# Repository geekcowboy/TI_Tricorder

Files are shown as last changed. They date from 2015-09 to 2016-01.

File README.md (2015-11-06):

Prototyping the Future: The Mark I Tricorder Project

For 50 decades, Star Trek has served as an inspiration for engineers and makers alike. Many of the tech concepts of 1960s science fiction has turned into 21st century everyday reality.  One of the most beloved ideas was the all-in-one Tricorder that let the crew ascertain the status of countless environmental factors. The Tricorder of the Captain Kirk and Mr. Spock may still be a few generations away, but what if the Mark I version of the Tricorder was invented tody?

This project presents one intriguing possibility.  Highlighting the amazing micrcontroller and sensor technology of today, we've built a Mark I Tricorder prototype.  Leveraging the out-of-this-world capabilities of the new TI MSP432P401R LaunchPad, we've put a ton of sensors in a conventient BoosterPack form factor.

Some highlights of the Tricorder BoosterPack:

- HDC1000 Humidity Sensor
- LMT70 Temperature Sensor
- OPT3001 Ambient Light Sensor
- MAG3110 Magnetometer
- LMP91000 Electrochemical Sensor Interface
- PGA900 Programmable Resistive Sensing Conditioner
- microSD Card reader
- Peripheral Module (Pmod) Type I GPIO Interface 
- 2 user defined buttons / 1 reset button
- 2 user defined LEDs / 1 power indicator LED

Coming Soon:  Shopping Cart BOM @ Mouser Electronics

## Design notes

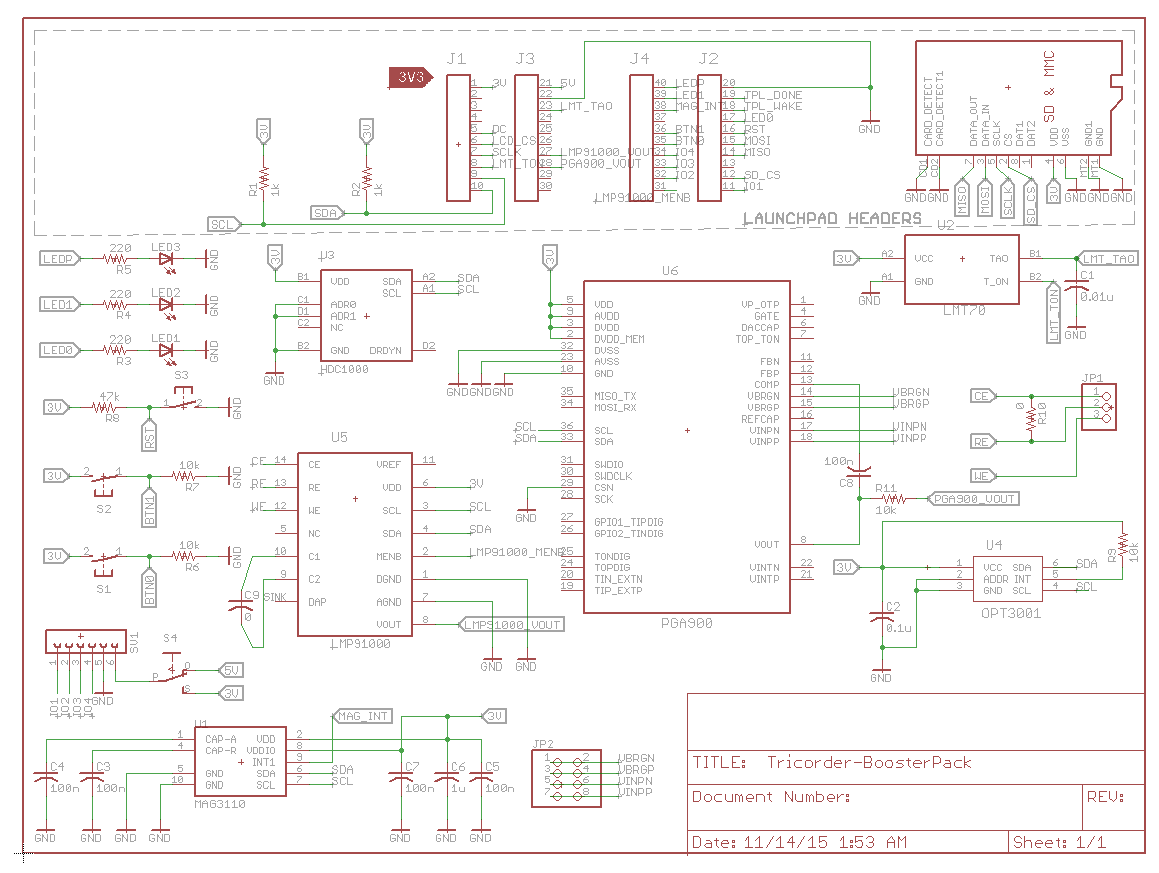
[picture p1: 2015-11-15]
Documentation/v1_1/Tricorder_Schematic_v1_1.png

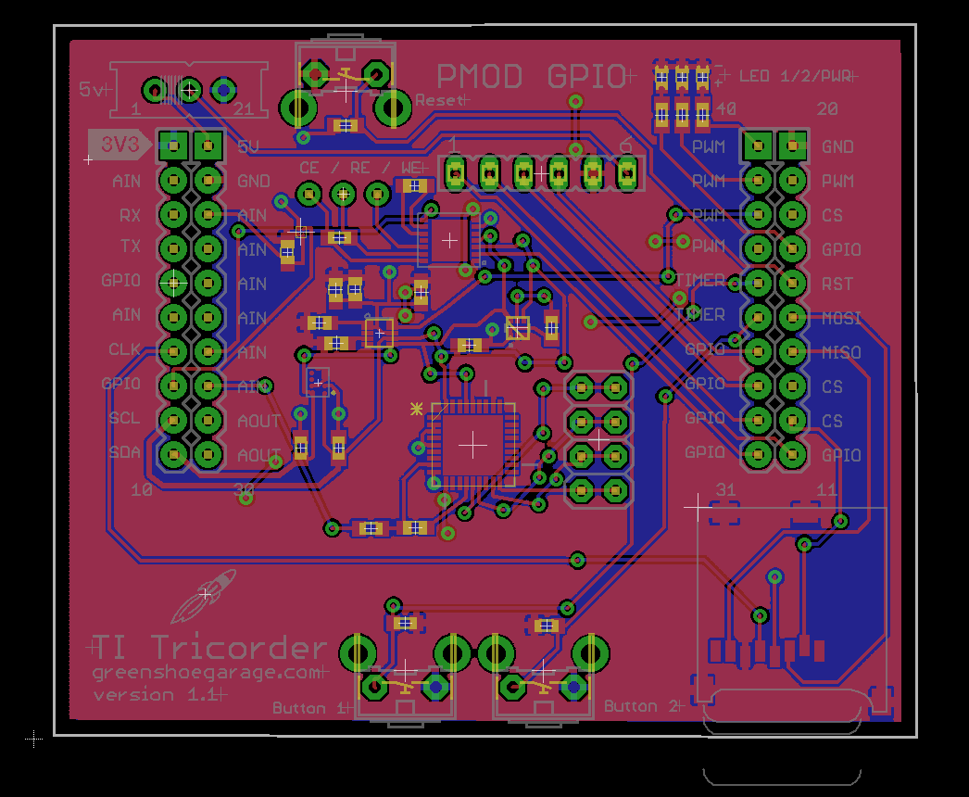
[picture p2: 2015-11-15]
Documentation/v1_1/Tricorder_PCB_Layout_v1_1.png

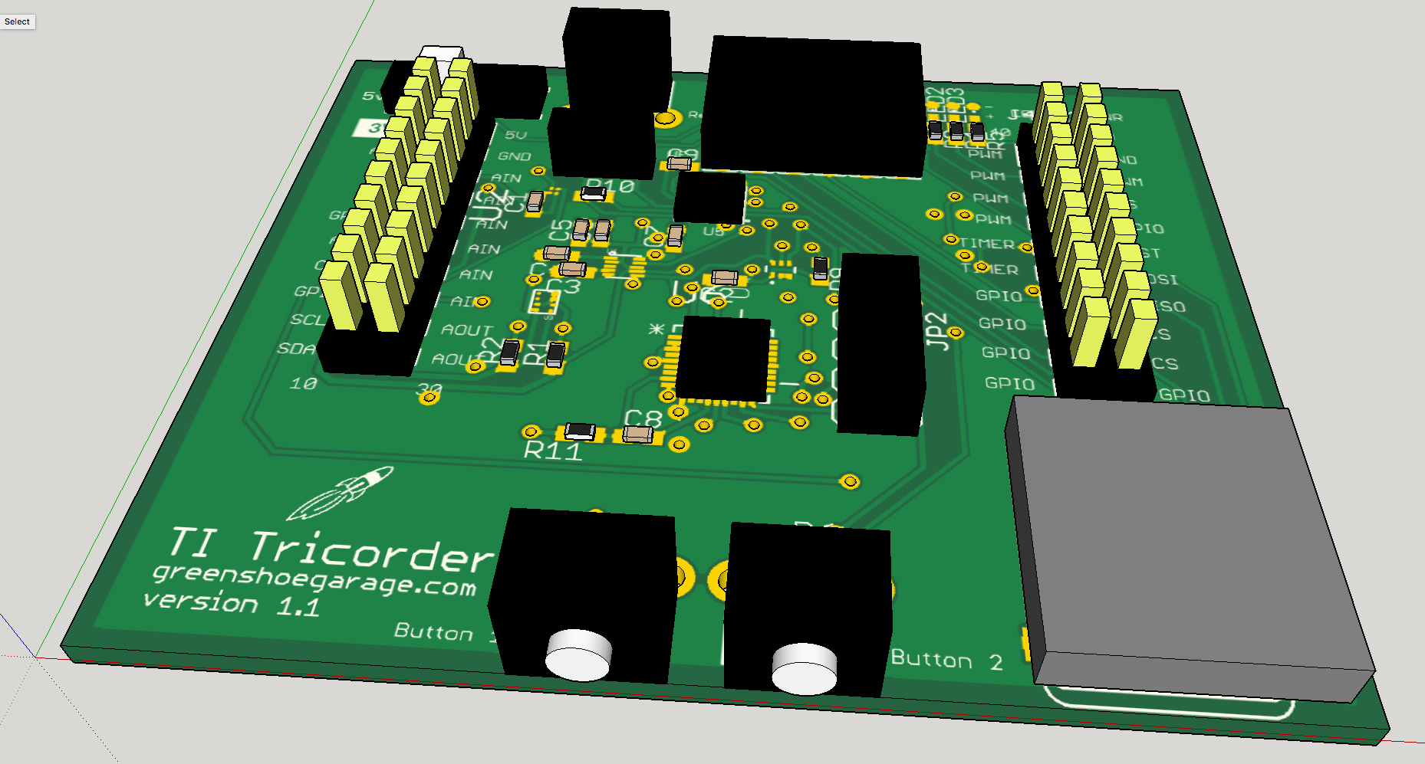
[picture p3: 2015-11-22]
Documentation/v1_1/PCBA_3D_v1_1.png

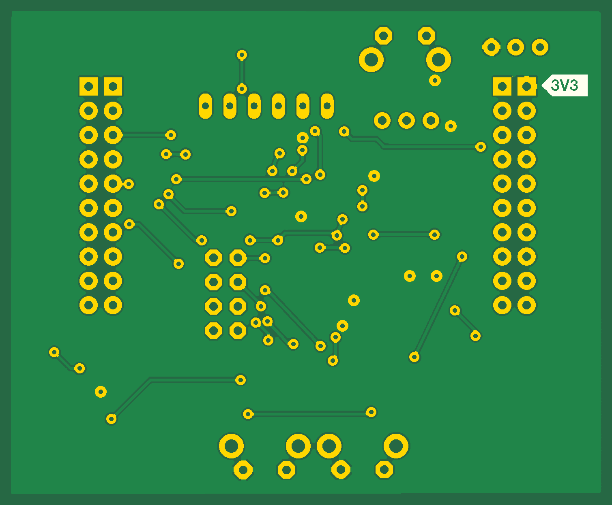
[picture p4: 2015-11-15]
EAGLE BoosterPack/v1_1/eagleUp/eagleUp_Tricorder-BoosterPack_board_bottom.png

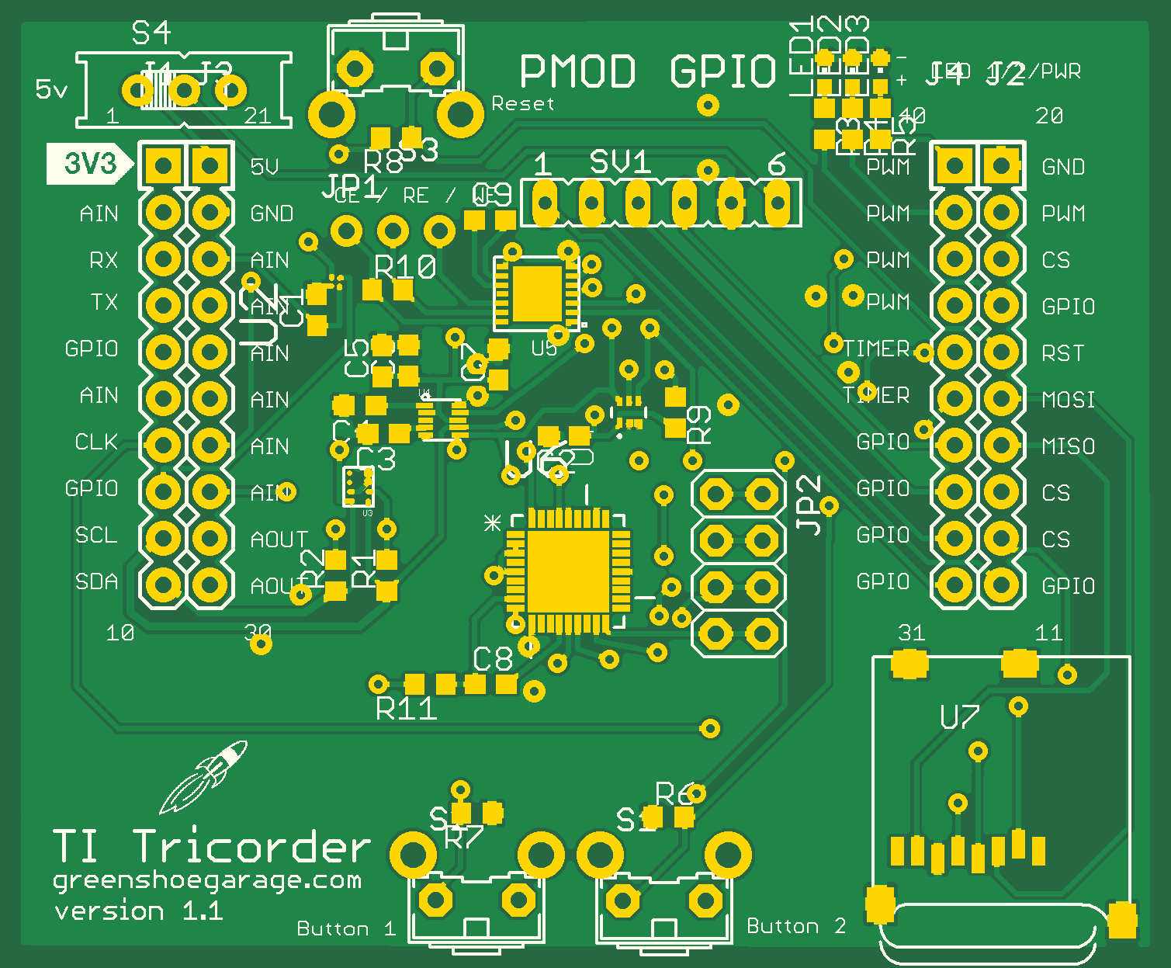
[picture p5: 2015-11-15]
EAGLE BoosterPack/v1_1/eagleUp/eagleUp_Tricorder-BoosterPack_board_top.png

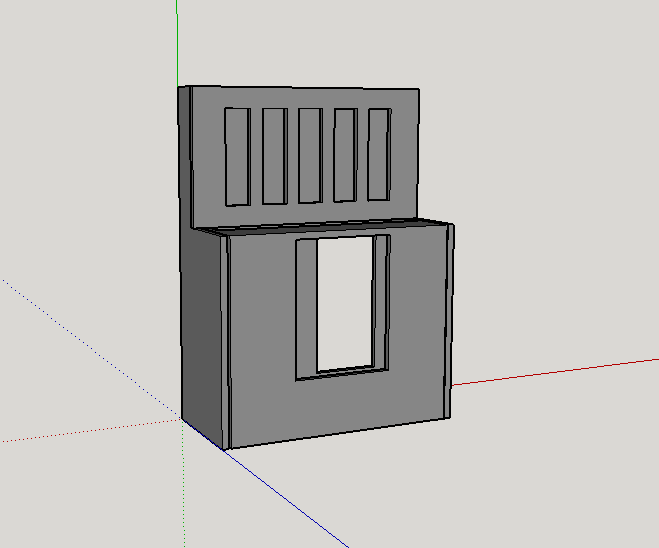
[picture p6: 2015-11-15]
Documentation/v1_1/Enclosure_3D_v1_1.png

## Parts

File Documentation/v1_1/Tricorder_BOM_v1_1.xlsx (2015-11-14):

Qty | Part | Value | Device | Package | Description | Manufacturer | Mfr Part # | Notes | SMD Caps | 8
2 | A1, A2 |  | HEADER2X10-BOOSTERPACK | SSHQ-110-D-08-G-LF | STACKABLE HEADERS, 2x10 (QTY: 2) | Major Leage Electronics | SSHQ-110-D-10-G-LF |  | SMD Resistor | 11
1 | C1 | 0.01u | C-USC0603 | C0603 | CAPACITOR, American symbol | Kemet | C0603C103K5RACTU |  | Headers | 5
6 | C2, C3, C4, C5, C7, C8 | 100n | C-USC0603 | C0603 | CAPACITOR, American symbol | Kemet | C0603C104K5RACTU |  | Switches | 1
1 | C6 | 1u | C-USC0603 | C0603 | CAPACITOR, American symbol | Kemet | C0603C105K4RACTU |  | Ics | 6
1 | C9 | DNP | C-USC0603 | C0603 | CAPACITOR, American symbol | DNP | Do Not Populate
1 | JP1 |  | PINHD-1X3 | FEMALE 1X03 | FEMALE HEADER | Sullins | PPPC031LFBN-RC | http://www.digikey.com/product-detail/en/PPPC031LFBN-RC/S7036-ND/810175
1 | JP2 |  | PINHD-2X4 | FEMALE 2X04 | FEMALE HEADER | Sullins | PPTC042LFBN-RC | http://www.digikey.com/product-detail/en/PPTC042LFBN-RC/S7072-ND/810211
2 | LED1, LED2 |  | LEDCHIPLED_0603 | CHIPLED_0603 | RED LED | Avago | HSMH-C190
1 | LED3 |  | LEDCHIPLED_0603 | CHIPLED_0603 | GREEN LED | Avago | HSMG-C190
2 | R1, R2 | 1k | R-US_R0603 | R0603 | RESISTOR | Vishay | CRCW06031K00FKEA
3 | R3 R4, R5 | 220 | R-US_R0603 | R0603 | RESISTOR | Vishay | CRCW0603220RFKEA
4 | R6, R7, R9, R11 | 10k | R-US_R0603 | R0603 | RESISTOR | Vishay | CRCW060310K0FKEA
1 | R8 | 47k | R-US_R0603 | R0603 | RESISTOR | Vishay | CRCW060347K0FKEA
1 | R10 | DNP | R-US_R0603 | R0603 | RESISTOR | DNP | Do Not Populate
3 | S1, S2, S3 |  | B3F-3100 RIGHT ANGLE BUTTON | B3F-3100 | OMRON SWITCH | Omron | B3F-3100
1 | S4 |  | EG1218S SLIDE SWITCH | EG1218S SLIDE SWITCH | SLIDING SWITCH | Eswitch | EG1218 | http://www.digikey.com/product-detail/en/EG1218/EG1903-ND/101726
1 | SV1 |  | PINHD-1X6 RIGHT ANGLE | FEMALE 1X06 RIGHT ANGLE | FEMALE RIGHT ANGLE HEADER | Sullins | PPPC061LGBN-RC | http://www.digikey.com/product-detail/en/PPPC061LGBN-RC/S5481-ND/775939
1 | U1 | MAG3110 | MAG3110 | DFN-10 | 3-axis digital (I2C) magnetometer | Freescale | MAG3110FCR1 (http://www.mouser.com/ProductDetail/Freescale-Semiconductor/MAG3110FCR1/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)
1 | U2 | LMT70 | LMT70 | BGA4C40P2X2_77X77X50 | Temperature Sensor | Texas Instruments | LMT70YFQT (http://www.mouser.com/ProductDetail/Texas-Instruments/LMT70YFQT/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)
1 | U3 | HDC1000 | HDC1000 | DSBGA_8_YPA | Humidity Sensor | Texas Instruments | HDC1000YPAT
1 | U4 | OPT3001 | OPT3001 | SOT23-6 | Ambient Light Sensor | Texas Instruments | OPT3001DNPR
1 | U5 | LMP91000 | LMP91000 | WFDFN-14 | Electrochemical Sensor Interface | Texas Instruments | LMP91000SD/NOPB
1 | U6 | PGA900 | PGA900 | QFN50P600X600X90-37N | Programmable Resistive Sensing Conditioner | Texas Instruments | PGA900ARHHT
1 | U7 | MICROSD | MICROSD | MICROSD CARD HOLDER | MicroSD Card Reader, Surface Mount | 3M | 2908-05WB-MG

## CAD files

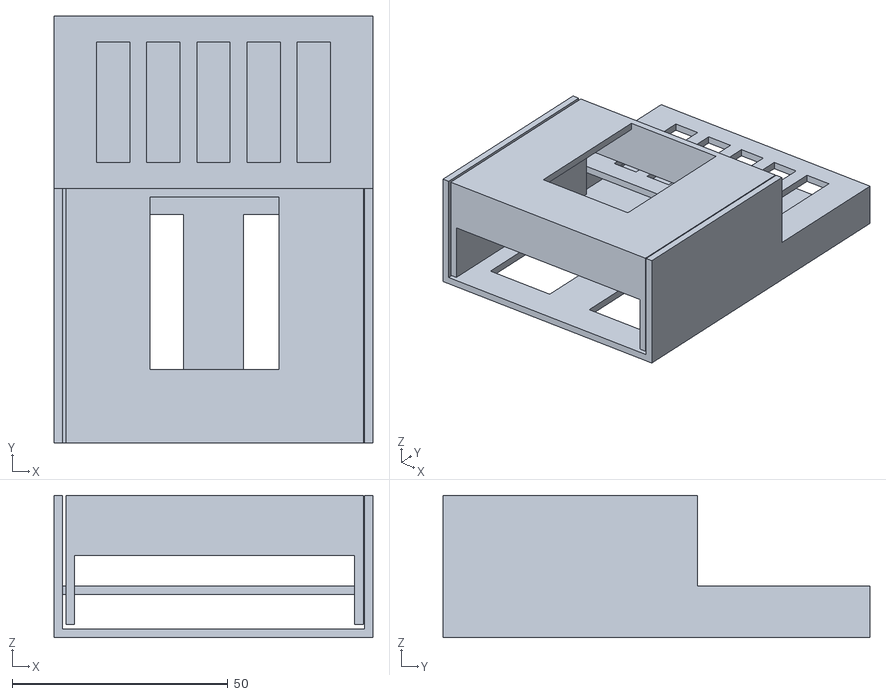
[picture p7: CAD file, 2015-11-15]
3D Files/v1_1/Tricorder_Assembled.stl
74.0 x 99.0 x 33.0

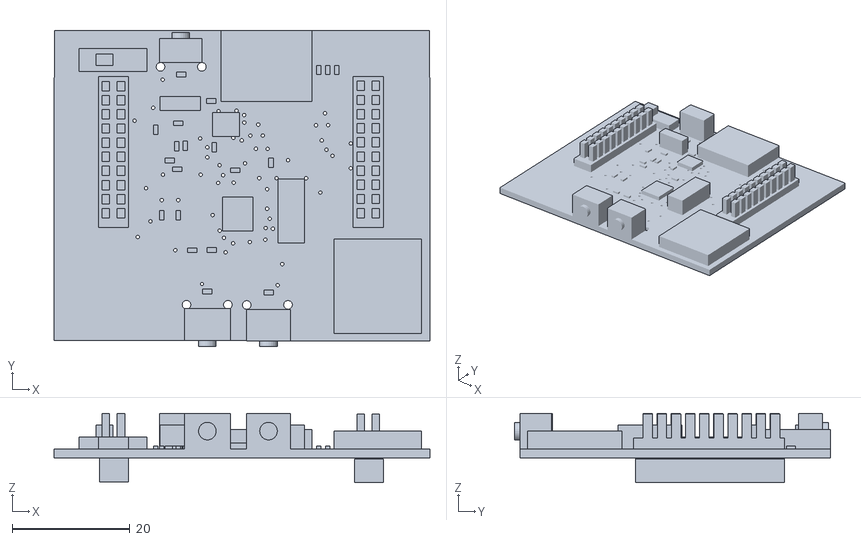
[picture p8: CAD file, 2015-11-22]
3D Files/v1_1/PCBA_v1_1.stl
63.8 x 53.7 x 11.7

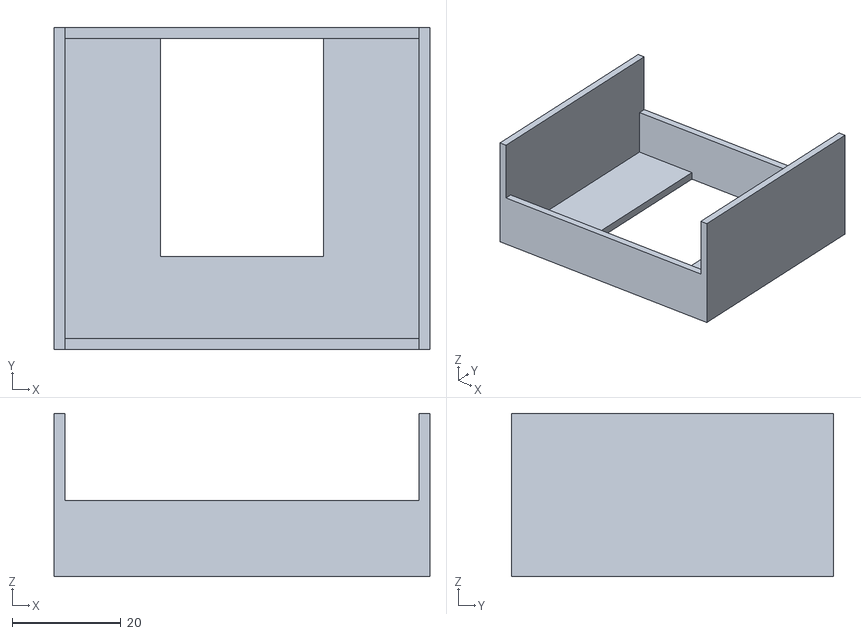
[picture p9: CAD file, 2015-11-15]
3D Files/v1_1/DisplayCase.stl
69.0 x 59.0 x 30.0

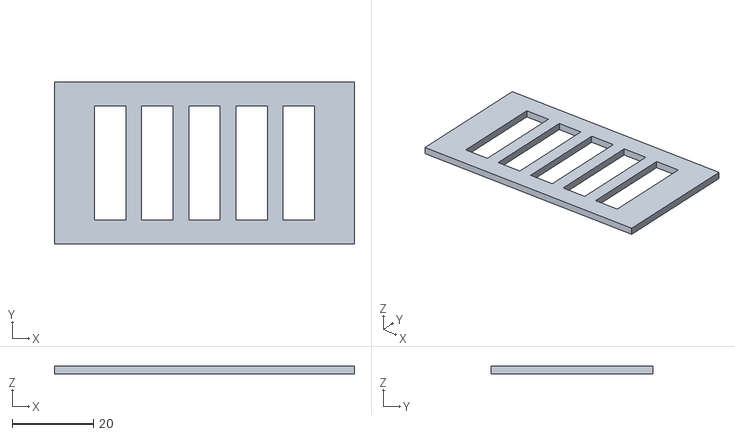
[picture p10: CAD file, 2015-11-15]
3D Files/v1_1/Tricorder_VentShield.stl
74.0 x 40.0 x 2.00

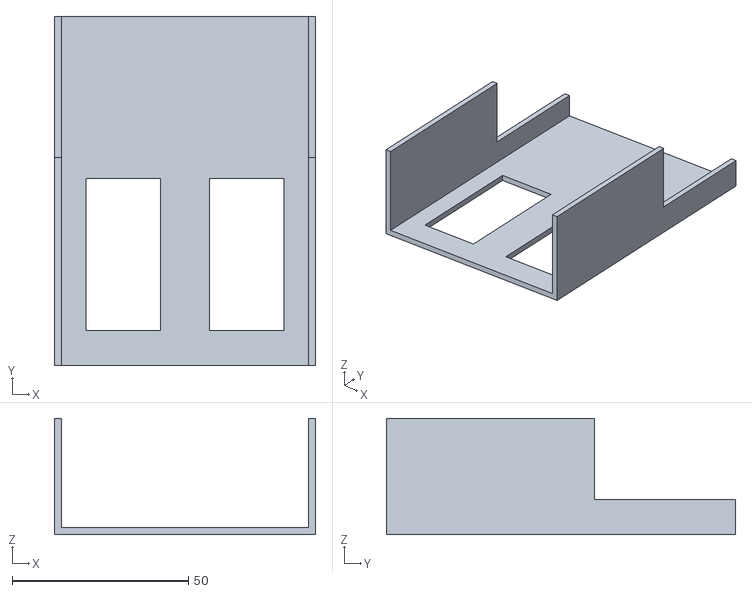
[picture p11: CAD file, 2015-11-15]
3D Files/v1_1/TricorderBottom.stl
74.0 x 99.0 x 33.0

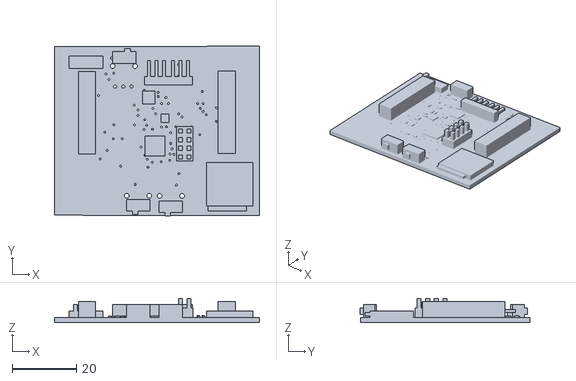
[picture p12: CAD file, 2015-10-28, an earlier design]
3D Files/v1_0/PCB_rev2_3D.stl
63.8 x 52.8 x 7.60

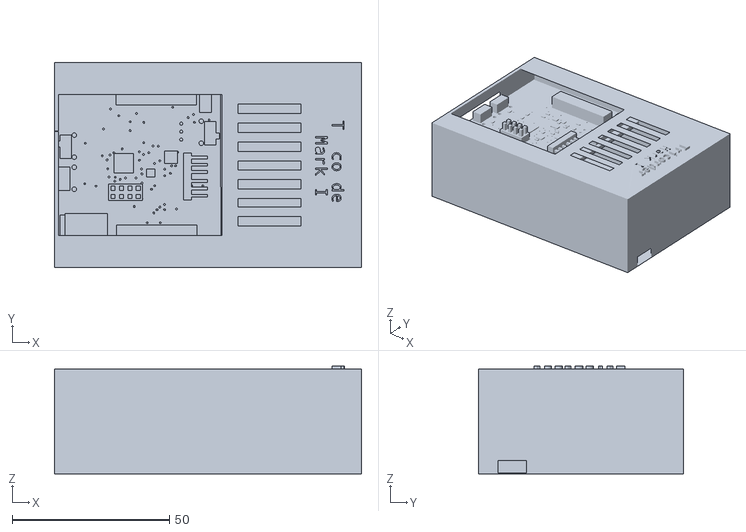
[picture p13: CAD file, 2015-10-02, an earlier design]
3D Files/v1_0/Tricorder_Concept_rev2.stl
97.6 x 65.3 x 34.3

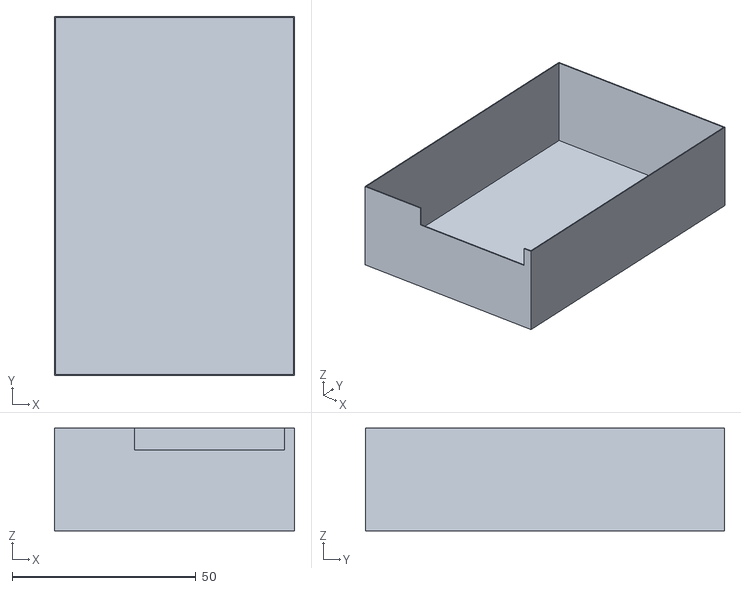
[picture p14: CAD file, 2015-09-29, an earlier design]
3D Files/v1_0/Tricorder_BottomEnclosure_rev2.stl
65.3 x 97.6 x 28.0

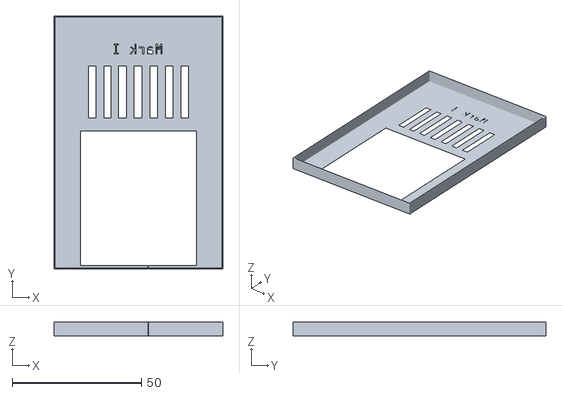
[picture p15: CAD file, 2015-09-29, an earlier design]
3D Files/v1_0/Tricorder_EnclosureTop_rev2.stl
65.3 x 97.6 x 5.33

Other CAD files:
3D Files/v1_0/PCB_rev2_3D.skp
3D Files/v1_0/Tricorder_BottomEnclosure_rev2.skp
3D Files/v1_0/Tricorder_Concept_rev2.skp
3D Files/v1_0/Tricorder_EnclosureTop_rev2.skp
3D Files/v1_1/DisplayCase.skp
3D Files/v1_1/PCBA_v1_1.skp
3D Files/v1_1/PCBA_v1_1~.skp
3D Files/v1_1/TricorderBottom.skp
3D Files/v1_1/Tricorder_Assembled.skp
3D Files/v1_1/Tricorder_VentShield.skp

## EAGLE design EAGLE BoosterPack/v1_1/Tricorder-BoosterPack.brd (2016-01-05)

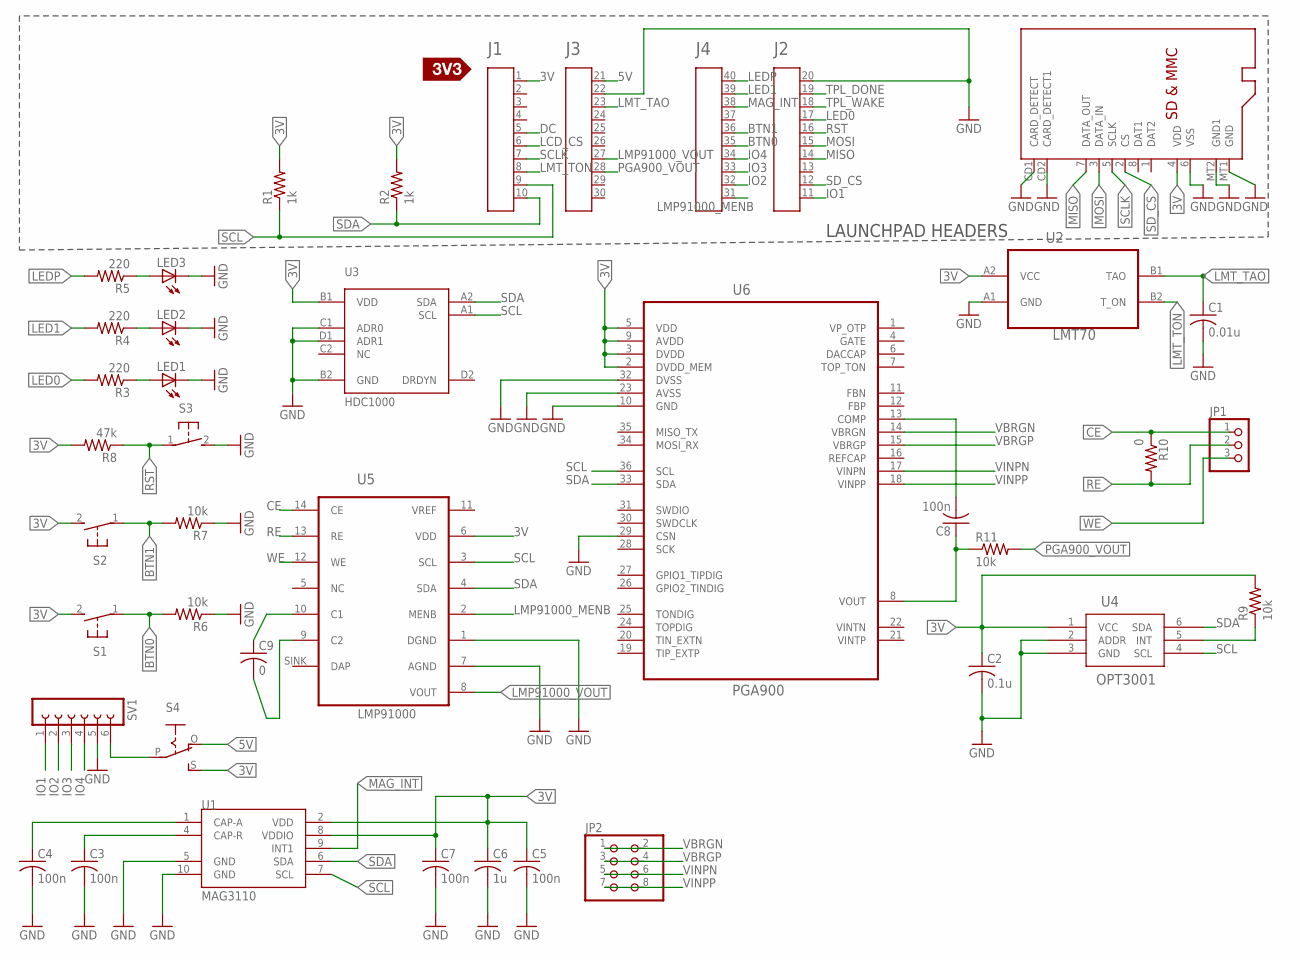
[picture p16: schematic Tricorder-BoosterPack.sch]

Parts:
A1: HEADER4X10-BOOSTERPACK; 4X10-BOOSTERPACK
C1: 0.01u; C0603
C2: 0.1u; C0603
C3, C4, C5, C7, C8: 100n; C0603
C6: 1u; C0603
C9: 0; C0603
JP1: PINHD-1X3CB; 1X03-CLEANBIG
JP2: PINHD-2X4; 2X04
LED1, LED2, LED3: LEDCHIPLED_0603; CHIPLED_0603
R1, R2: 1k; R0603
R3, R4, R5: 220; R0603
R6, R7, R9, R11: 10k; R0603
R8: 47k; R0603
R10: 0; R0603
S1, S2, S3: 31-XX; B3F-31XX
S4: EG1218S; EG1218
SV1: FE06-1; FE06
U1: MAG3110; DFN-10
U2: LMT70LMT70; BGA4C40P2X2_77X77X50
U3: HDC1000; DSBGA_8_YPA
U4: OPT3001; DPK6
U5: LMP91000; WFDFN-14; DIGIKEY LMP91000
U6: PGA900; QFN50P600X600X90-37N
U7: MICROSD
U$3: SILK_3V3_TAG

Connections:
3V: A1.1, C2.1, C5.1, C6.1, C7.1, R1.2, R2.2, R8.2, R9.2, S1.2 (S), S2.2 (S), S4.S, U1.2 (VDD), U1.8 (VDDIO), U2.A2 (VCC), U3.B1 (VDD), U4.1 (VCC), U5.6 (VDD), U6.2 (DVDD_MEM), U6.3 (DVDD), U6.5 (VDD), U6.9 (AVDD), U7.4 (VDD)
5V: A1.21, S4.O
BTN0: A1.35, R6.2, S1.1
BTN1: A1.36, R7.2, S2.1
CE: JP1.1, R10.1, U5.14 (CE)
DC: A1.5
GND: A1.20, A1.22, C1.2, C2.2, C3.2, C4.2, C5.2, C6.2, C7.2, LED1.C, LED2.C, LED3.C, R6.1, R7.1, S3.2 (S), SV1.5, U1.5 (GND), U1.10 (GND), U2.A1 (GND), U3.B2 (GND), U3.C1 (ADR0), U3.D1 (ADR1), U4.2 (ADDR), U4.3 (GND), U5.1 (DGND), U5.7 (AGND), U6.10 (GND), U6.23 (AVSS), U6.29 (CSN), U6.32 (DVSS), U7.6 (VSS), U7.CD1 (CARD_DETECT), U7.CD2 (CARD_DETECT1), U7.MT1 (GND), U7.MT2 (GND1)
IO1: A1.11, SV1.1
IO2: A1.32, SV1.2
IO3: A1.33, SV1.3
IO4: A1.34, SV1.4
LCD_CS: A1.6
LED0: A1.17, R3.2
LED1: A1.39, R4.2
LEDP: A1.40, R5.2
LMP91000_MENB: A1.31, U5.2 (MENB)
LMP91000_VOUT: A1.27, U5.8 (VOUT)
LMT_TAO: A1.23, C1.1, U2.B1 (TAO)
LMT_TON: A1.8, U2.B2 (T_ON)
MAG_INT: A1.38, U1.9 (INT1)
MISO: A1.14, U7.7 (DATA_OUT)
MOSI: A1.15, U7.3 (DATA_IN)
unnamed: LED1.A, R3.1
unnamed: LED2.A, R4.1
unnamed: LED3.A, R5.1
unnamed: S4.P, SV1.6
unnamed: R9.1, U4.5 (INT)
unnamed: C9.1, U5.10 (C1)
unnamed: C3.1, U1.4 (CAP-R)
unnamed: C4.1, U1.1 (CAP-A)
unnamed: C8.2, U6.13 (COMP)
unnamed: C9.2, U5.9 (C2)
unnamed: C8.1, R11.1, U6.8 (VOUT)
PGA900_VOUT: A1.28, R11.2
RE: JP1.2, R10.2, U5.13 (RE)
RST: A1.16, R8.1, S3.1
SCL: A1.9, R1.1, U1.7 (SCL), U3.A1 (SCL), U4.4 (SCL), U5.3 (SCL), U6.36 (SCL)
SCLK: A1.7, U7.5 (SCLK)
SDA: A1.10, R2.1, U1.6 (SDA), U3.A2 (SDA), U4.6 (SDA), U5.4 (SDA), U6.33 (SDA)
SD_CS: A1.12, U7.2 (CS)
TPL_DONE: A1.19
TPL_WAKE: A1.18
VBRGN: JP2.1, JP2.2, U6.14 (VBRGN)
VBRGP: JP2.3, JP2.4, U6.15 (VBRGP)
VINPN: JP2.5, JP2.6, U6.17 (VINPN)
VINPP: JP2.7, JP2.8, U6.18 (VINPP)
VREF: U5.11 (VREF)
WE: JP1.3, U5.12 (WE)

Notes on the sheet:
LAUNCHPAD HEADERS

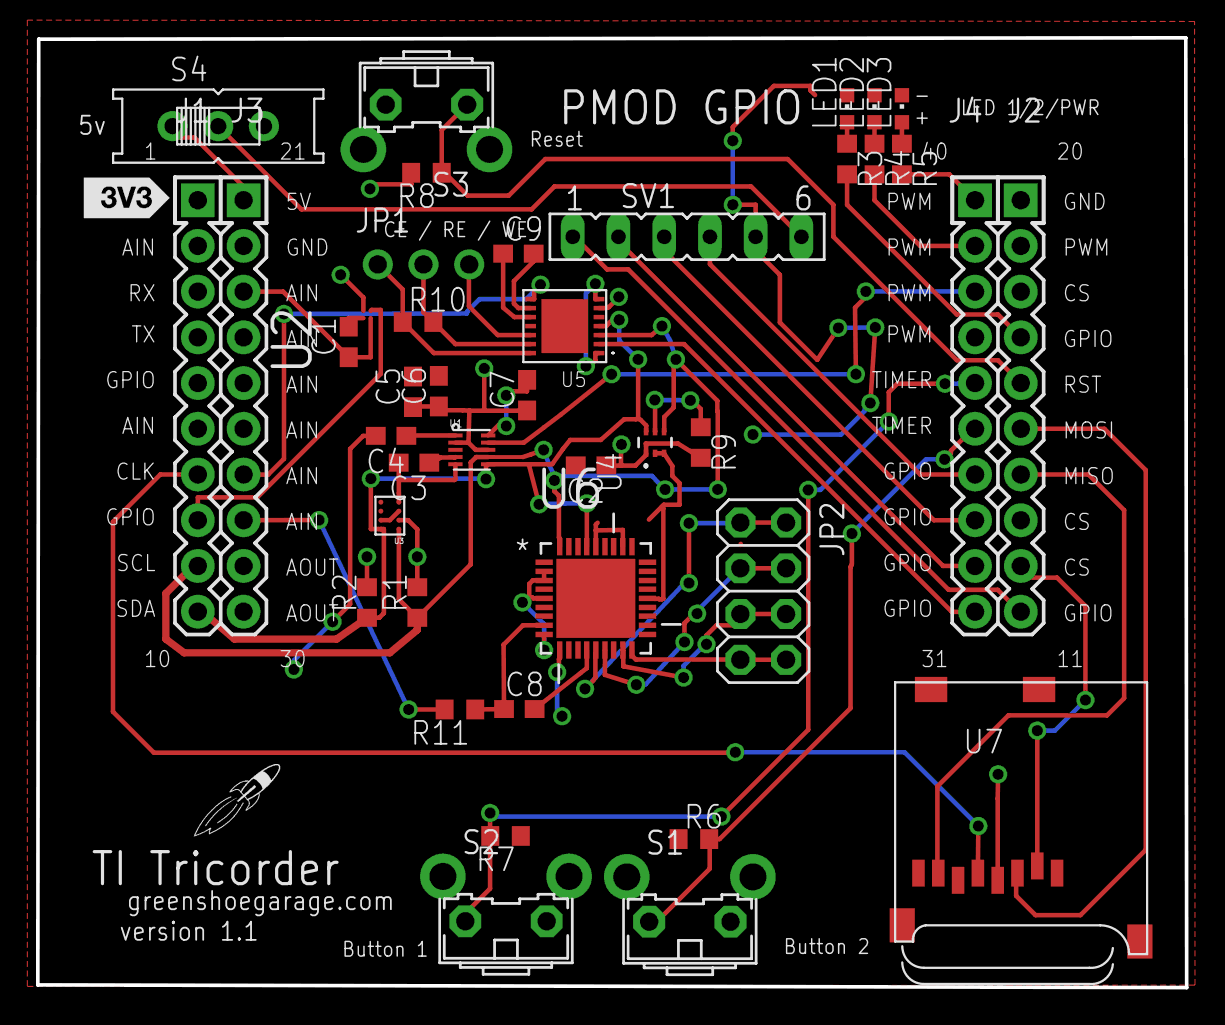
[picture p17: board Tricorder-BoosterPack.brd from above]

Board: 2 copper layers, 63.8 x 52.8 mm, 40 parts (0 on the bottom side), 43 nets.

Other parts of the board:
U$2: LOGO-ROCKET

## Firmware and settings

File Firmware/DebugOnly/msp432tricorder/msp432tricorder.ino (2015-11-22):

//
//  MSP432Tricoder
//  Example main.cpp for MSP432P401R-based Tricorder BoosterPack
//
//
//  Date   :  Sep 12, 2015
//  Version:  1.00
//  File   :  MSP432Tricorder.ino
//
//  Licence CC = BY SA NC
//
//  Use of Clock from Galaxia library for MSP432 proposed by ReiVilo
//

//
//LIBRARIES
//
#include <TricorderSupport.h>


//
// #DEFINEs and Global Variables
//
int sensorCounter = 0;
boolean goLeft = false;
boolean goRight = false;


// 
//DATA STRUCTURES
//
struct tricorderSensors
{
  String sensorID;
  String UM;
  float sensorVal;
};


//
// INSTANTIATE DEVICES
//
TricorderSupport tricorder;
tricorderSensors tricorderSensor[numSensors];


//
//Function: SETUP
//
void setup() {  
  // Setup I/O
  pinMode(powerLED, OUTPUT);
  pinMode(LED0, OUTPUT);
  pinMode(LED1, OUTPUT);
  pinMode(leftButton, INPUT_PULLUP);
  pinMode(rightButton, INPUT_PULLUP);

  //Initialize system
  digitalWrite(powerLED, HIGH);  // Turn on power indicator LED
  digitalWrite(LED0, LOW);  // Turn off LED0
  digitalWrite(LED1, LOW);  // Turn off LED1


  // Initatize sensors and data fields
  tricorderSensor[HDC1000_id].sensorID ="HDC1000";
  tricorderSensor[HDC1000_id].UM = "% Humidity";
  tricorderSensor[HDC1000_id].sensorVal = -1;
  tricorderSensor[LMT70_id].sensorID ="LMT70";
  tricorderSensor[LMT70_id].UM = "Degrees F";
  tricorderSensor[LMT70_id].sensorVal = -1;
  tricorderSensor[OPT3001_id].sensorID ="OPT3001";
  tricorderSensor[OPT3001_id].UM = "Lux";
  tricorderSensor[OPT3001_id].sensorVal = -1;
  tricorderSensor[MAG3110_id].sensorID ="MAG3110";
  tricorderSensor[MAG3110_id].UM = "uT";
  tricorderSensor[MAG3110_id].sensorVal = -1;
  tricorderSensor[LMP91000_id].sensorID ="O2 Sensor";
  tricorderSensor[LMP91000_id].UM = "ppm";
  tricorderSensor[LMP91000_id].sensorVal = -1;
  tricorderSensor[PGA900_id].sensorID ="Pressure";
  tricorderSensor[PGA900_id].UM = "kPa";
  tricorderSensor[PGA900_id].sensorVal = -1;

  // Initialize Serial Stream
  Serial.begin(9600);
  Serial.println("Tricorder Mk I");

  //Get first reading
  tricorder.begin();
  tricorderSensor[HDC1000_id].sensorVal = tricorder.read_HDC1000();
}


//
// Function: LOOP
//
void loop() {
  // Check for navigation button presses
  goRight = digitalRead(rightButton);
  delay(debounceDelay);
  goLeft = digitalRead(leftButton);
  delay(debounceDelay);

  if (!goRight) {
    sensorCounter++;
  }

  if (!goLeft) {
    sensorCounter--;
  }

  if (sensorCounter < 0) {
    sensorCounter = numSensors - 1;
  }
  else if (sensorCounter > numSensors-1)
  {
    sensorCounter = 0;
  }


  //Update sensor reading based on sensor selected by user
  switch (sensorCounter) {
  case HDC1000_id:
    tricorderSensor[HDC1000_id].sensorVal = (float)tricorder.read_HDC1000();
    break;
    
  case LMT70_id:
    tricorderSensor[LMT70_id].sensorVal = (float)tricorder.read_LMT70();
    break;
    
  case OPT3001_id:
    tricorderSensor[OPT3001_id].sensorVal = (float)tricorder.read_OPT3001();
    break;
    
  case MAG3110_id:
    tricorderSensor[MAG3110_id].sensorVal = (float)tricorder.read_MAG3110();
    if (tricorderSensor[MAG3110_id].sensorVal < 30000) {
      digitalWrite(LED1, HIGH);
    }
    else {
      digitalWrite(LED1, LOW);
    }
    break;
    
  case LMP91000_id:
    tricorderSensor[LMP91000_id].sensorVal = (float)tricorder.read_LMP91000();
    break;
    
  case PGA900_id:
    tricorderSensor[PGA900_id].sensorVal = (float)tricorder.read_PGA900();
    break;
    
  default:
    sensorCounter = 0;
    tricorderSensor[HDC1000_id].sensorVal = (float)tricorder.read_HDC1000();
  }

  // Display selected sensor data
  displayData(tricorderSensor[sensorCounter].sensorID, tricorderSensor[sensorCounter].UM, tricorderSensor[sensorCounter].sensorVal);
}


//
// Function: displayData
//
void displayData(String sensorID, String UM, float sensorVal) {
   Serial.print(sensorID);
   Serial.print(" : ");
   Serial.print(sensorVal);
   Serial.print(" ");
   Serial.println(UM);
   delay(100);
}

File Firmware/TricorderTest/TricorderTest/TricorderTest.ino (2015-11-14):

int led0 = 17;
int led1 = 39;
int pled = 40;

void setup()
{
  // put your setup code here, to run once:
  pinMode(pled, OUTPUT);
  pinMode(led0, OUTPUT);
  pinMode(led1, OUTPUT);
}

void loop()
{
  // put your main code here, to run repeatedly:
  digitalWrite(pled,HIGH);
  delay(1000);
  digitalWrite(led1,HIGH);
  delay(1000);
  digitalWrite(led0,HIGH);
  delay(3000);
  digitalWrite(led0,LOW);
  delay(1000);
  digitalWrite(led1,LOW);
  delay(1000);
  digitalWrite(pled,LOW);
  delay(3000);
}

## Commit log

2015-07-04 Schematic Capture v001
    Initial schematic capture of major external/large components (e.g.
    switch, PMOD interface). Initial PCB layout with copper fill for GND.
    No routing.
    [Tricorder-BoosterPack.brd, Tricorder-BoosterPack.sch]
2015-07-05 Pin Assignment .xlsx
    Lists of pin assignment for devices to the BoosterPack standard
    [Tricorder Pin Assignment.xlsx]
2015-09-12 SCH/BRD update, Init firmware
    Added 4 main sensors to schematic and PMOD, buttons, LEDs, necessary
    peripheral components.
    Initial firmware release.
    [Tricorder-BoosterPack.brd, Tricorder-BoosterPack.sch]
2015-09-13 Initial enclosure design
    First pass at an enclosure for the Tricorder project. Designed to be
    3D printed.
    [PCB_3D.skp, Tricorder-BoosterPack.brd, Tricorder_BottomEnclosure.skp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]
2015-09-14 Hardware Lock
    Hardware design locked for TI review and approval. 3D CAD files
    updated to reflect new PCB dimensions.
    [PCB_3D.skp, PCB_3D~.skp, Tricorder Pin Assignment.xlsx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]
2015-09-14 STL Files
    Added STL files for 3D printed enclosure.
    [Tricorder_BottomEnclosure.skp, Tricorder_BottomEnclosure.stl, Tricorder_BottomEnclosure~.skp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]
2015-09-21 LMP91000 and Alphasense O2-A1 Sensor
    Reconfigured board to include a TI LMP91000 gas sensor I2C interface
    chip and placeholder for Alphasense O2-A1 oxygen sensor
    [Tricorder Pin Assignment.xlsx, Tricorder-BoosterPack.brd, Tricorder-BoosterPack.sch]
2015-09-21 O2 Sensor Moved Offboard
    Replace onboard O2 sensor with header pins to allow for off board
    placement of sensor. Eagle files revised as well as documentation files.
    [PCB_3D.skp, Tricorder-BoosterPack.brd, Tricorder-BoosterPack.sch]
2015-09-21 Updated PCB STL file
    Updated PCB STL file
    [PCB_3D.stl]
2015-09-25 v2 PCB Layout
    Revamped the PCB layout to make room for a PGA900 and Honeywell
    Pressure Sensor
    [Tricorder-BoosterPack.brd, Tricorder-BoosterPack.sch]
2015-09-27 PGA900 w/ Male Headers for Resistive Senor Offboard
    Added the PGA900 Programmable Resistive Sensing Conditioner IC and male
    header to allow external resistive pressure sensor
    [PCB_3D.skp, PCB_3D.stl, PCB_3D~.skp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]
2015-09-27 Added components to 3D visualization
    Added components to 3D visualization such as ICs, switches, buttons,
    and LEDs
    [PCB_rev2_3D.skp, PCB_rev2_3D.stl, PCB_rev2_3D~.skp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]
2015-09-29 Completed PGA900 circuit, add microSD card reader
    Completed PGA900 circuit, add microSD card reader
    [PCB_rev2_3D.skp, PCB_rev2_3D.stl, PCB_rev2_3D_old.skp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]
2015-10-02 Hardware Design Lock
    Short of finding any showstopper bugs, the hardware design and BOM is
    locked.
    [Tricorder-BoosterPack.brd, Tricorder-BoosterPack.sch, Tricorder_BOM.xlsx]
2015-10-02 Update Documentation
    Updated documentation to reflect final hardware design.
    [PCB_rev2_3D.skp, PCB_rev2_3D.stl, PCB_rev2_3D~.skp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]
2015-10-11 MAG3110 Circuit Fix
    Removed R10, renumbered components
    [Tricorder-BoosterPack.brd, Tricorder-BoosterPack.sch, Tricorder_BOM.xlsx]
2015-10-16 Revised BOM
    [LMT70_Calculator.xlsx, Tricorder-BoosterPack.brd, Tricorder-BoosterPack.sch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]
2015-10-28 v1.0 Hardware sent to Fab
    Removed rev1 and locked rev2 design files, hardware sent to fab house.
    [PCB-AE-Turnkey Quote-Michael Parks - Tricorder.xls, PCB_3D.skp, PCB_3D.stl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]
2015-10-31 BOM Update
    [PCB-AE-Turnkey Quote-Michael Parks - Tricorder.xls]
2015-11-03 BOM revision
    [PCB-AE-Turnkey Quote-Michael Parks - Tricorder.xls]
2015-11-04 revised TricorderSupport.h
    [PCB-AE-Turnkey Quote-Michael Parks - Tricorder.xls]
2015-11-06 updated documentation
    [LMT70_Calculator.xlsx, PCB_rev2_3D.skp, PCB_rev2_3D.stl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]
2015-11-14 v1.1
    board corrections and code corrections
    [LMT70_Calculator.xlsx, Tricorder Pin Assignment rev2.xlsx, Tricorder-BoosterPack.brd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]
2015-11-14 v1.1 BOM Updates
    [Tricorder_BOM_rev2.xlsx]
2015-11-15 new enclosure design (v1.1)
    [DisplayCase.skp, DisplayCase.stl, TricorderBottom.skp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]
2015-11-15 updated document names to reflect new version (v1.1)
    [Tricorder Pin Assignment v1_1.xlsx, Tricorder_BOM_v1_1.xlsx]
2015-11-15 new gerber and image files
    [PCBA_v1_1.skp, PCBA_v1_1.stl, Tricorder-BoosterPack.brd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]
2015-11-22 3D files revised
    [PCBA_v1_1.skp, PCBA_v1_1.stl, PCBA_v1_1~.skp]
2016-01-05 revised brd and sch
    [Tricorder-BoosterPack.brd, Tricorder-BoosterPack.sch]

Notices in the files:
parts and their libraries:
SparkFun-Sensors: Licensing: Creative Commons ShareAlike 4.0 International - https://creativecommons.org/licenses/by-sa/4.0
